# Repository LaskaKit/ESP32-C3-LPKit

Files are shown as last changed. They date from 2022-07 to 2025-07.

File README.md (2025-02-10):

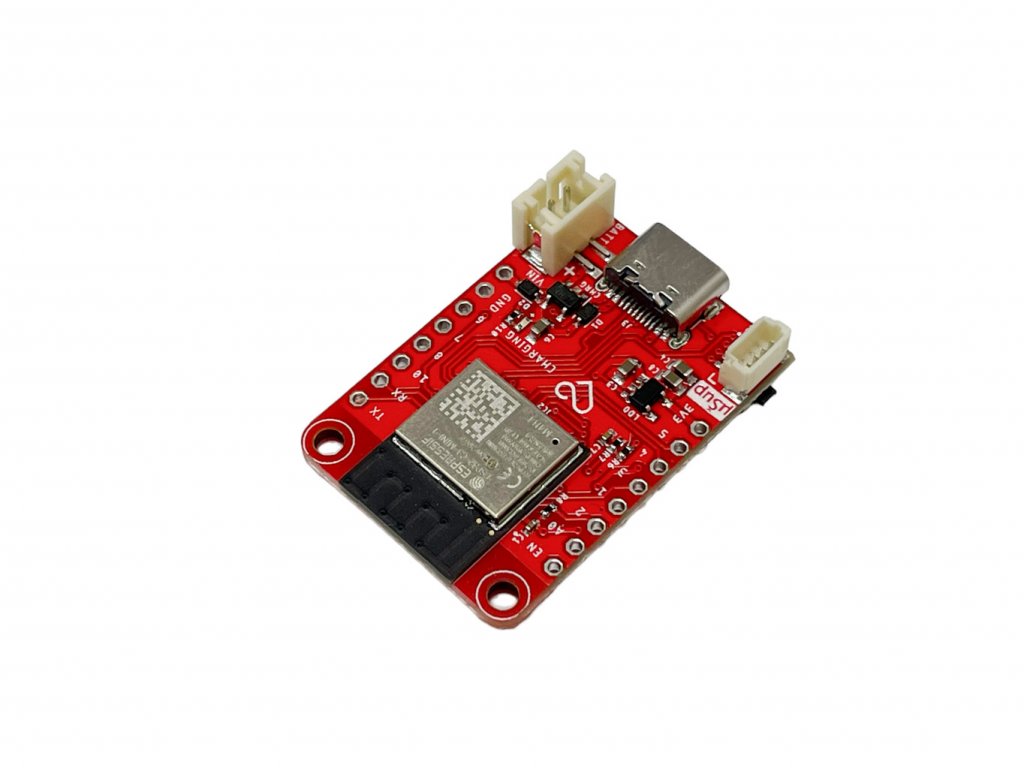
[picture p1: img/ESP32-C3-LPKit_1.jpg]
LaskaKit ESP32-C3-LPKit

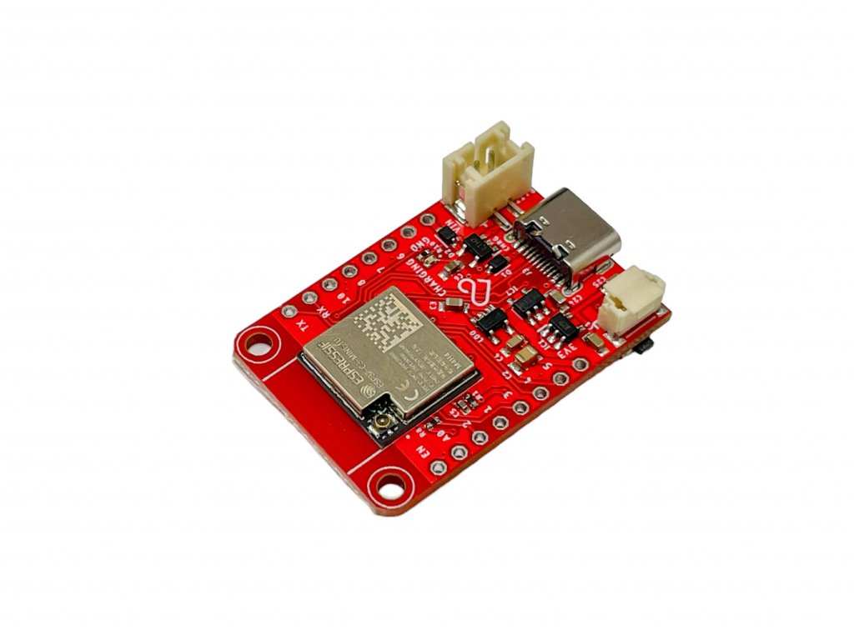
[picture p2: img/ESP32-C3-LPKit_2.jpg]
LaskaKit ESP32-C3-LPKit

# LaskaKit ESP32-C3-LPKit 

The LaskaKit [ESP32-C3-LPKit](https://www.laskakit.cz/laskkit-esp-12-board/?variantId=10482) development board is based on the popular Wi-Fi/Bluetooth ESP32-C3, which is widely supported by both the manufacturer and the bastling community.

The board is pin-to-pin and size compatible with the Wemos D1 Mini. Even though the [ESP32-C3-LPKit](https://www.laskakit.cz/laskkit-esp-12-board/?variantId=10482) includes a programmer like the popular Wemos D1 Mini, it achieves much lower power consumption and a low-power voltage regulator.</br>
This makes it much more energy efficient. So if you are looking for a compatible board and want to save power at the same time, then the ESP32-C3-LPKit is for you.

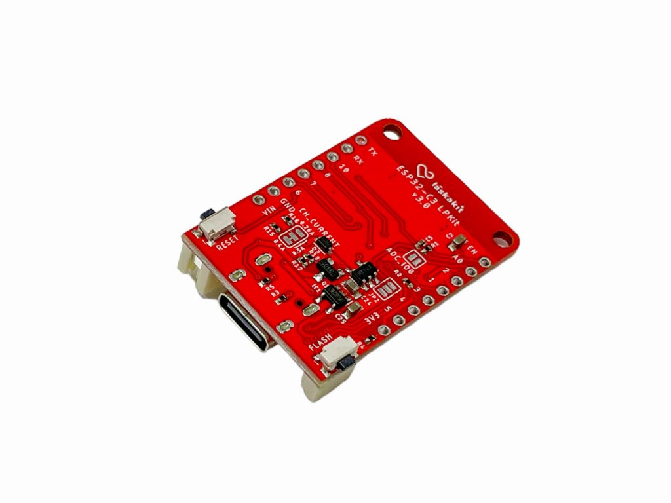
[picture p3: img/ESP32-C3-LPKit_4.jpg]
LaskaKit ESP32-C3-LPKit


The ESP32-C3-LPKit also includes a charging circuit for the battery, which is charged from USB-C or from the VIN pin. The charging current is selected by a solder bridge on the bottom of the board. The default setting is 400mA.</br>
The voltage measurement of the connected battery is disabled-unconnected by default (solder bridge on the bottom of the PCB). Either the battery (solder bridge) or the voltage connected on pin A0 (solder bridge) can be connected to the ESP32-C3. The measured voltage (battery/external input) is divided by voltage divider. The analog input for measured votlage is GPIO0.

It is necessary to add a definition on which PINs is I2C initiating the i2c module: Wire.begin(8, 10); // (8,10) -> ESP32-C3-LPKit v2; (19,18) -> ESP32-C3-LPKit v1

To program, you need to put the chip in bootloader mode.</br>
**Simply press the FLASH button and press and release RESET. Then release the FLASH button as well.**</br>
On Windows OS you should hear the characteristic sound of the newly connected device.</br>

For the older version of the ESP32-C3-LPKit you need a programmer, not only for them we have created a [suitable programmer](https://www.laskakit.cz/laskakit-ch9102-programmer-usb-c--microusb--uart/), with which programming this board will be a total breeze. When using our programmer, it is no longer necessary to press any buttons before the actual programming. Switching to programming mode is automatic.

| ESP module | 	ESP32-C3 | 
|---|---|
| Input voltage | 	3,7-8V | 
| Current in deep-sleep mode | 7μA | 
| Digital I/O Pins | 9 | 
| Analog inputs | 5 | 
| Dimensions |
| Length |34.2mm | 
| Width | 25.6mm | 
| Height | 7mm | 
| Weight | 8.26g | 

**The board is available on https://www.laskakit.cz/laskkit-esp-12-board/?variantId=10482**

Pinout
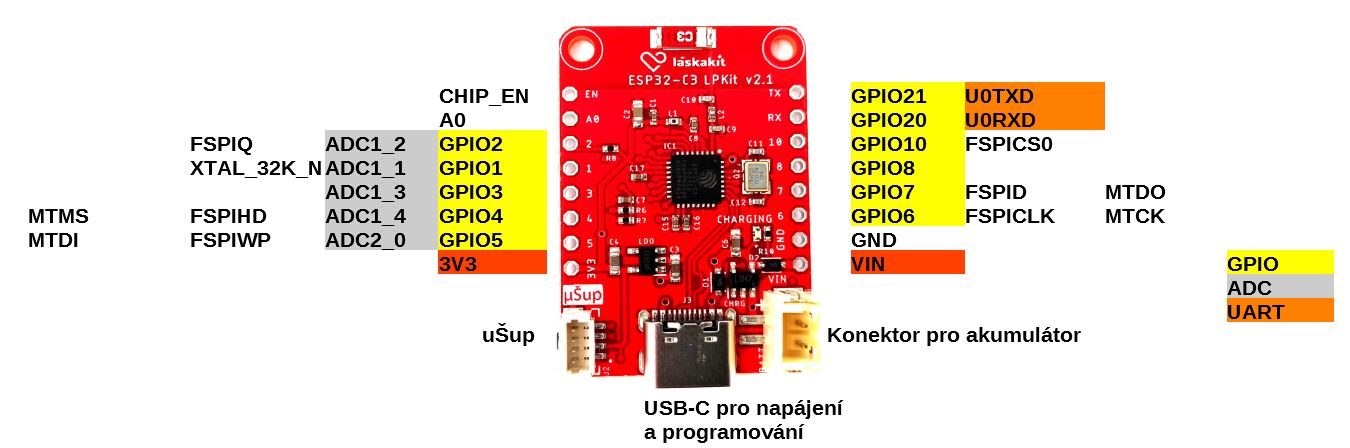
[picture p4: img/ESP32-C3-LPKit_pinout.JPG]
LaskaKit ESP32-C3-LPKit pinout

Battery voltage measurement connections for v3.2:
* Battery voltage measurement: left side JP2 + left side ADC_IO0
* Voltage measurement on pin A0, max. 4.2V: right side JP2 + left side ADC_IO0
* Voltage measurement on pin A0, max. 2.450V: JP2 not connected + right side ADC_IO0
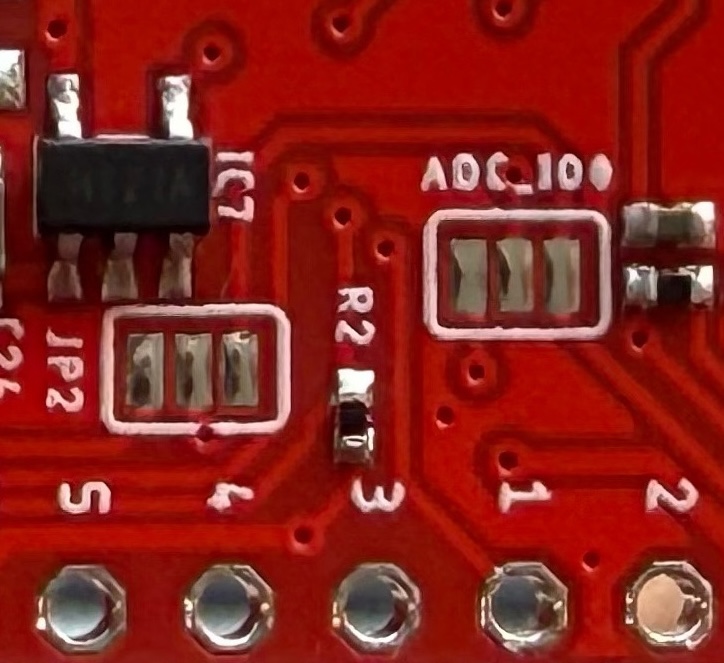
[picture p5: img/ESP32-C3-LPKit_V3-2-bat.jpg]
pinout LaskaKit ESP32-C3-LPKit


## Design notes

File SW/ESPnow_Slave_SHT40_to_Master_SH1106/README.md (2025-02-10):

# ESPnow - Slave odešle teplotu a vlhkost do Master, Master je zobrazí na OLED displeji

## SLAVE zařízení </br>
Vzorový kód pro využití ESPnow, přes které jsou odeslány teplota a vlhkost vzduchu</br>
Upozornění: je nezbytné zkopírovat MAC adresu z MASTER zařízení do SLAVE (masterMAC[])
Nejprve nahraj MASTER kód do ESP32-C3 LPkit a ESP32-C3 zobrazí svou MAC adresu,
kterou zapíšeš do SLAVE kódu a nahraješ do SLAVE zařízení.
</br>
## MASTER zařízení</br>
Vzorový kód pro využití ESPnow. SLAVE zařízení změří teplotu a vlhkost a odešle
do MASTER zařízení, které hodnoty vypíše do Serial a na OLED displej</br>
Upozornění: je nezbytné zkopírovat MAC adresu z MASTER zařízení do SLAVE (masterMAC[])
Nejprve nahraj MASTER kód do ESP32-C3 LPkit a ESP32-C3 zobrazí svou MAC adresu,
kterou zapíšeš do SLAVE kódu a nahraješ do SLAVE zařízení.</br>
</br>
## Hardware:</br>
https://www.laskakit.cz/laskkit-esp-12-board/?variantId=10482</br>
v popřípadě verze s externí anténou pak dokoupit anténu a pigtail</br>
https://www.laskakit.cz/pigtail-mhf3-ipex3-sma-female--kabel-1-15mm--15cm/</br>
https://www.laskakit.cz/laskakit-sht40-senzor-teploty-a-vlhkosti-vzduchu/</br>
https://www.laskakit.cz/laskakit-oled-displej-128x64-1-3--i2c/?variantId=11903</br>
</br>
## ESP32 package - 2.0.17 </br>
ESP library verze</br>
ESP32 library 3.0.x</br>
Podmínka: Tools -> pokud USB CDC On Boot is ENABLED potom</br>
Serial zmaneá nativní/vestavěné USB</br>
Tools -> pokud USB CDC On Boot je DISABLED potom</br>
Serial znamená UART (Piny RX a TX)</br>
</br>
ESP32 library 2.0.xy</br>
Podmínka: Tools -> USB CDC On Boot musí být zakázaný</br>
potom použijte USBSerial k poslání dat na nativní/vestavěné USB </br>

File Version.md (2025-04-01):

### Version 4.0
- Redo power line, LDO chnaged to RT9080
- + Neopixel LED
- + µŠup SPI connector
- ADC changed back to simplicity
#### Version 3.3
- Přidány I2C pullup rezistory
#### Version 3.2
- Změna jumperu ADC_IO0 na dvoucestný, aby bylo možné připojit pin A0 napřímo na IO0 bez napěťového děliče na desce.
#### Version 3.1
#### Version 3.0
- Předeláno na ESP32-C3-MINI (deep sleep 11 µA)
#### Version 2.1
- Doladěny hodnoty Pi článku antény
- IPEX anténa/SMD anténa - rozdělení na samostatné desky
- Přidána propojka na odpojení odporového děliče od baterie
#### Version 2.0
- Switched to bare C3 IC | Změna IO na holý C3
#### Version 1.2
- Adjusted resistor values in the resistance divider to 1M/1.3M, ADC max. input voltage stays the same. | Upraveny hodnoty rezistorů v odporovém děliči na 1M/1.3M, ADC max. vstupní napětí zůstává stejné. 
- BOOT button renamed to RESET | Přejmenováno tlačítko BOOT na RESET.
#### Version 1.1
- Voltager devider changed to 100k/130k ADC max. input voltage is 4.423 V | Dělič napětí změněn na 100k/130k ADC max. vstupní napětí je 4,423 V
#### Version 1.0
- Initial | Počáteční

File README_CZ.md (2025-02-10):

LaskaKit ESP32-C3-LPKit
LaskaKit ESP32-C3-LPKit

# LaskaKit ESP32-C3-LPKit 

Vývojová deska [LaskaKit ESP32-C3-LPKit](https://www.laskakit.cz/laskkit-esp-12-board/?variantId=10482) založena na populárním Wi-Fi/Bluetooth ESP32-C3, který je široce podporován jak výrobcem, tak i komunitou bastlířů. 

Deska je pinově a rozměrově kompatibilní s Wemos D1 Mini. I přesto, že [ESP32-C3-LPKit](https://www.laskakit.cz/laskkit-esp-12-board/) obsahuje programátor stejně jako populární Wemos D1 Mini, dosahuje daleko nižší spotřeby energie a ssamozřejmě i úspornější stabilizátor napětí.</br>
Díky tomu je energeticky mnohem úspornější. Pokud tedy hledáš kompatibilní desku a zároveň chcete šetřit energii, pak ESP32-C3-LPKit je pro Tebe jako určený.

LaskaKit ESP32-C3-LPKit

ESP32-C3-LPKit obsahuje i nabíjecí obvod pro akumulátor, ten se nabíjí z USB-C nebo z pinu VIN. Nabíjecí proud se volí pájecím mostem na spodní straně desky. Výchozí nastavení je 400mA.</br>
Měření napětí připojeného akumulátoru je ve výchozím stavu zakázáno-nepřipojeno (pájecí most na spodní straně DPS). Do ESP32-C3 může být připojeno měření napětí buď akumulátoru (pájecí most) nebo napětí připojené na pinu A0 (pájecí most). Napětí připojené na A0 je sníženo o poměr napěťového děliče. Analogový vstup pro měření napětí je GPIO0.

Je potřeba před iniciací i2c modulu přidat definici na kterých PINech jsou: Wire.begin(8, 10); // (8,10) -> ESP32-C3-LPKit v2; (19,18) -> ESP32-C3-LPKit v1

Pro naprogramování je potřeba dostat čip do režimu nahrávání. </br>
**Stačí zmáčknout tlačítko FLASH a zmáčknout a pustit RESET. Poté pustit i tlačítko FLASH** </br>
U OS Windows byste měli uslyšet charakteristický zvuk nově připojého zařízení.</br>

Pro staší verzi ESP32-C3-LPKit je potřeba programátor, nejen k nim jsme [vytvořili vhodný programátor](https://www.laskakit.cz/laskakit-ch340-programmer-usb-c--microusb--uart/), se kterým bude programování této desky naprostá hračka. Při použití tohoto našeho programátoru již není nutné před vlastním programováním mačkat žádná tlačítka. Přepnutí do režimu programování je automatické.</br>

| ESP modul | 	ESP32-C3 | 
|---|---|
| Vstupní napětí | 	3,7-8V | 
| Odběr proudu v deep-sleep módu | 7μA | 
| Digitální I/O Piny | 9 | 
| Analogové Vstupy | 5 |
| Rozměry |
| Délka |34.2mm | 
| Šířka | 25.6mm | 
| Výška | 7mm | 
| Váha | 8.26g | 

**LaskaKit ESP32-C3-LPkit najdeš na https://www.laskakit.cz/laskkit-esp-12-board/?variantId=10482**

Pinout ESP32-C3-LPKit vidíš níže
LaskaKit ESP32-C3-LPKit pinout
Propojení pro měření napětí baterie pro v3.2:
* Měření napětí na baterii: leva strana JP2 + levá strana ADC_IO0
* Měření napětí na pinu A0, max. 4.2V: pravá strana JP2 + levá strana ADC_IO0
* Měření napětí na pinu A0, max. 2.450V: JP2 nezapojeny + pravá strana ADC_IO0
LaskaKit ESP32-C3-LPKit pinout

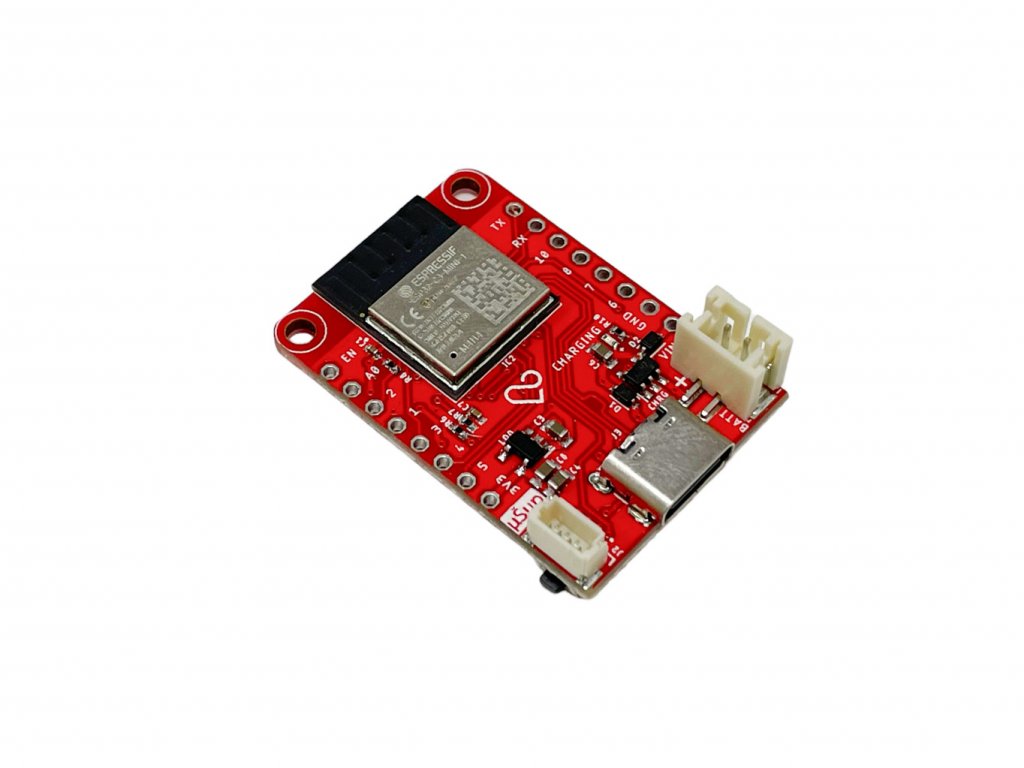
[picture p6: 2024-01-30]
img/ESP32-C3-LPKit_3.jpg

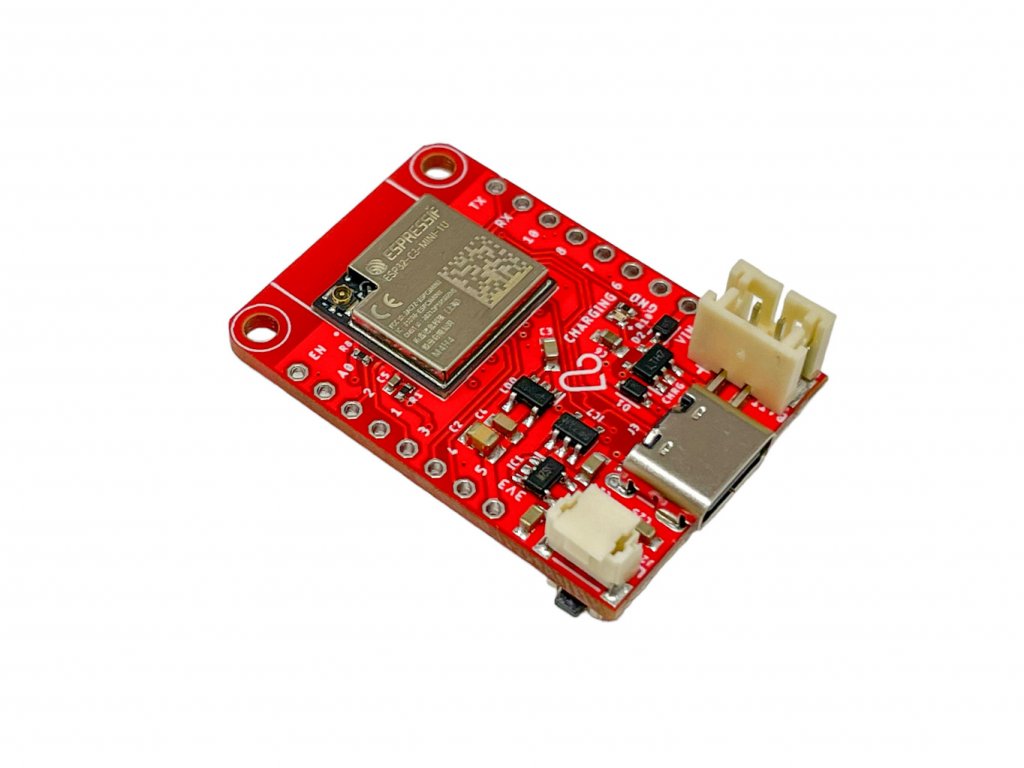
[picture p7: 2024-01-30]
img/ESP32-C3-LPKit_5.jpg

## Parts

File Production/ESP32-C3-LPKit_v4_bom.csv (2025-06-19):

Comment | Designator | Footprint | LCSC Part #
3.3k | R3 | R0402
4.7k | R14 | R0402
5.1k | R9 R10 | R0402
10k | R12 R15 R18 R22 | R0402
10uF/16V | C3 | C0603
22uF | C2 | C0603
47k | R19 R20 | R0402
100k | R13 | R0402
100nF | C1 | C0402
AO3401 | Q2 | SOT23
BAT60B | D3 | SOD323-R
DMG2305UX | Q6 | MICRO3 | C144153
ESP32-C3-MINI-1-N4 | IC2 | ESP32C3MINI1N4
JST-PH-2_SMD/SMD | P1 | B2B-PH-SM4 | C160352
JST-SH-4P | J2 | 1X04_1MM_RA_VERT | C371588
MMDT5401 | Q5 | SC70-6 | C54540
RED | CHARGING | CHIP-LED0603 | C2286
SK6812-EC20 | LED_IO9 | SK6812EC20
TP4054 | CH | SOT-23-5 | C32574
USB-C_GT-USB-7010B | J3 | G-SWITCH_GT-USB-7010B | C2837092
USUP_SPI_CONNECTOR_VERT | J1 | 1X06_1MM_RA_VERT | C145963
1.3M | R7 | R0402
1M | R6 | R0402
1k65 | R5 | R0402
3k3 | R11 | R0402
10k | R17 R21 | R0402
10uF/16V | C4 C6 C9 C13 | C0603
100nF | C5 C8 C14 | C0402
EN button | FLASH RESET | 1TS003B16003500A | C255808
LESD5D5.0CT1G | D8 D9 D10 | LESD5D50CT1G
RT9080-33GJ5 | LDO LDO_S | SOT94P280X100-5N

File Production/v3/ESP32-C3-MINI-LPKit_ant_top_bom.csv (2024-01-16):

Comment | Designator | Footprint | LCSC Part #
1k | R10 | R0402
1uF | C5 | C0402
1uF | C6 | C0603
10k | R1 R8 | R0402
22uF | C3 C24 | C0603
47uF | C1 C4 C25 | C0603
100uF | C2 | C0805
AP2191WG-7 | IC7 | SOT25 | C141321
BAT60B | D1 D2 | SOD323-R
ESP32-C3-MINI-1-N4 | IC2 | ESP32C3MINI1N4
HT7833 | LDO | SOT23-5
JST-PH-2/SMD | BATT | B2B-PH-SM4
JST-SH-4P | J2 | 1X04_1MM_RA_VERT | C371588
ME6211C33M5G | IC1 | SOT23-5
RED | CHARGING | CHIPLED_0402
TP4054 | CHRG | SOT-23-5
USB-C_2-16PIN | J3 | USBC_USB-C-16P-5 | C2837092
1.3M | R7 | R0402
1M | R6 | R0402
1TS003B-2000-3500A-CT | FLASH RESET | 1TS003B16003500A | C319396
1k65 | R15 | R0402
2M | R9 | R0402
3k3 | R16 | R0402
4.7k | R2 R4 | R0402
5k1 | R3 R5 | R0402
10k | R12 | R0402
100k | R13 | R0402
100nF | C7 | C0402
AO3401 | Q1 | SOT23
BAT60B | D3 | SOD323-R

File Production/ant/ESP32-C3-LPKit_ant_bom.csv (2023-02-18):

Comment | Designator | Footprint | LCSC Part #
1.3M | R7 | R0402
1M | R6 | R0402
1k | R10 | R0402
1uF | C3 C6 | C0603
2.4nH | L2 | L0402 | C90190
2.6p | C10 | C0402 | C2190109
2nH | L1 | L0402 | C145023
3.3p | C9 | C0402
10k | R8 | R0402
15p | C11 C12 | C0402
22uF | C2 C4 | C0603
40MHz | Q2 | 3.2X2.5_KX-7 | C9010
100nF | C1 C7 C8 C15 C16 C17 | C0402
BAT60B | D1 D2 | SOD323-R
CA-C03 | ANT | CA-C03
ESP32-C3FH4 | IC1 | QFN50P500X500X90-33N
HT7833 | LDO | SOT23-5
JST-PH-2/SMD | BATT | B2B-PH-SM4
JST-SH-4P | J2 | 1X04_1MM_RA_VERT | C239513
RED | CHARGING | CHIPLED_0402
TP4054 | CHRG | SOT-23-5
USB-C_2-16PIN | J3 | USBC_USB-C-16P-5 | C2837092
1TS003B-2000-3500A-CT | FLASH RESET | 1TS003B16003500A | C319396
1k65 | R15 | R0402
1uF | C5 | C0402
3k3 | R16 | R0402
5k1 | R3 R5 | R0402
10k | R1 R2 R4 R12 | R0402
10uF | C14 | C0603
100k | R13 | R0402
100nF | C13 | C0402
AO3401 | Q1 | SOT23
BAT60B | D3 | SOD323-R | C514095

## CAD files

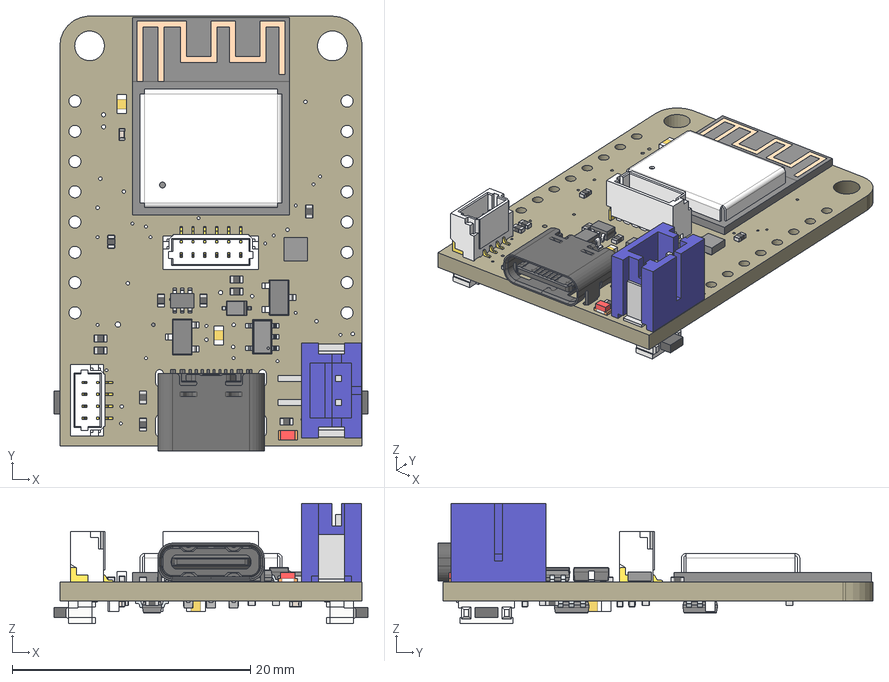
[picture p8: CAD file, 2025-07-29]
3D/ESP32-C3-LPKit_v4.step
26.4 x 36.5 x 10.1 mm
Board
Pin1 x 4
Pin2 x 4
CeramicBody x 4
LASKAKIT_HEART_4MM
LASKKIT_10MM_SILKSCREEN
1X04_1MM_RA_VERT
CHIP-LED0603
LESD5D50CT1G x 3
SC70-6
Pins
FilletPinL
FilletPinR
SOT23
2,5 x 2
ESP32C3MINI1N4
PinsArrayL
PinsArrayR
PinsArrayL (1) x 2
PinsArrayR (1) x 2
1TS003B16003500A x 2
C0603 x 6
R0402 x 17
MICRO3
USUP_4MM_SILKSCREEN
1X06_1MM_RA_VERT
B2B-PH-SM4
G-SWITCH_GT-USB-7010B

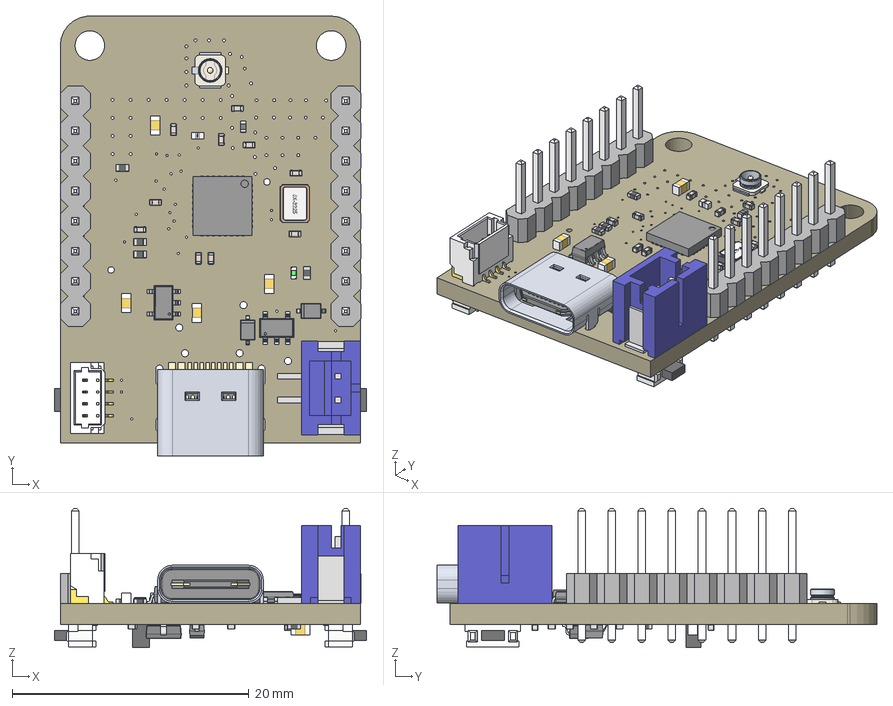
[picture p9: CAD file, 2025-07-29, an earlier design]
3D/old/ESP32-C3-LPKit_ipex_v2-1.step
26.4 x 37.2 x 11.8 mm
Board
L0402
base
SolderPad x 2
LASKAKIT_HEART_4MM
LASKKIT_10MM_SILKSCREEN
USUP_4MM_SILKSCREEN
1X04_1MM_RA_VERT
B2B-PH-SM4
U.FL_REDUCED_FOOTPRINT
USBC_USB-C-16P-5
CHIPLED_0402
SOT23
ThermalPin
PinsArrayLR
PinsArrayTB
PinsArrayL
PinsArrayR
PinsArrayL (1)
PinsArrayR (1)
3.2X2.5_KX-7
SMT-JUMPER_2_NO_SILK
Pin1 x 12
Pin2 x 12
CeramicBody x 12
1X08 x 2
FilletPinL x 3
FilletPinR x 3
2,5 x 2
1TS003B16003500A x 2
C0603 x 5
R0402 x 13

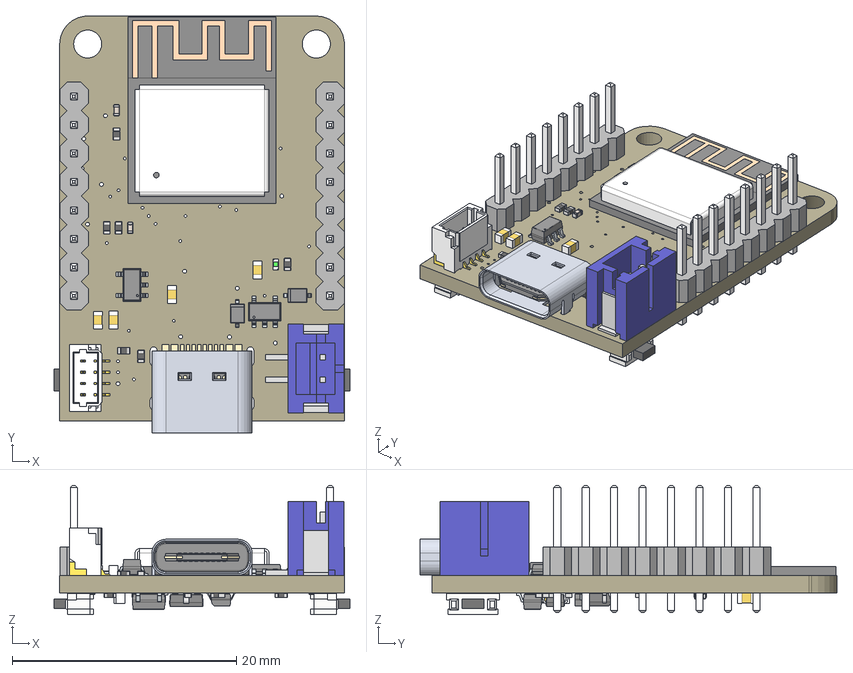
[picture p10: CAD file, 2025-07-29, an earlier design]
3D/old/ESP32-C3-LPKit_v3_3.step
26.4 x 37.2 x 11.5 mm
Board
Pin1 x 3
Pin2 x 3
CeramicBody x 3
LASKAKIT_HEART_4MM
LASKKIT_10MM_SILKSCREEN
USUP_4MM_SILKSCREEN
1X04_1MM_RA_VERT
1X08 x 2
B2B-PH-SM4
USBC_USB-C-16P-5
CHIPLED_0402
FilletPinL x 3
FilletPinR x 3
SOT23
2,5 x 2
ESP32C3MINI1N4
PinsArrayL
PinsArrayR
PinsArrayL (1) x 2
PinsArrayR (1) x 2
SOT25
1TS003B16003500A x 2
C0603 x 7
R0402 x 15

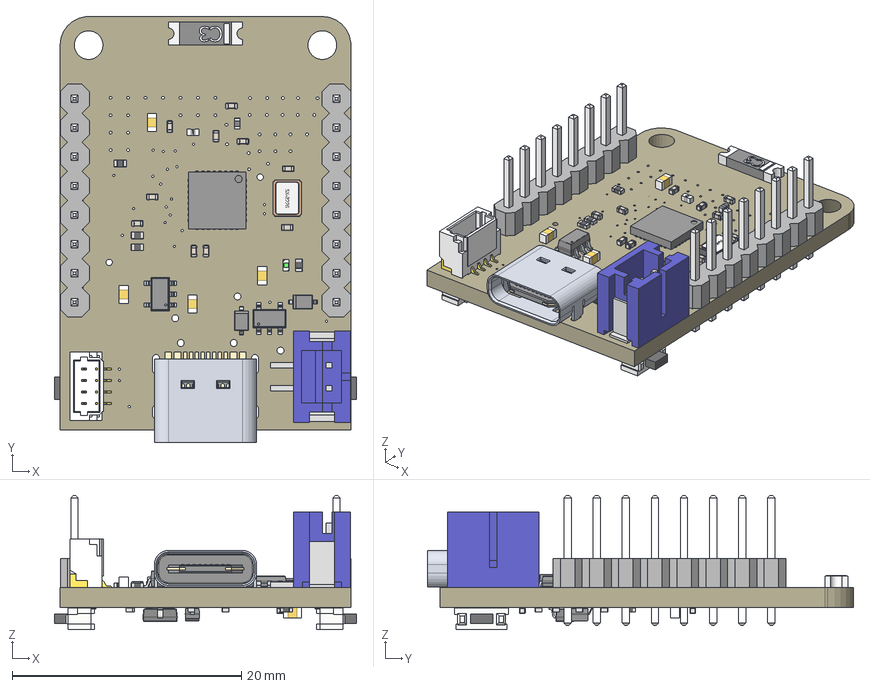
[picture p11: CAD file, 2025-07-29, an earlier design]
3D/old/ESP32-C3-LPKit_ant_v2-1.step
26.4 x 37.2 x 11.7 mm
Board
MainBody
Left
Right
SilkScreenMark
C3
L0402
base
SolderPad x 2
LASKAKIT_HEART_4MM
LASKKIT_10MM_SILKSCREEN
USUP_4MM_SILKSCREEN
1X04_1MM_RA_VERT
B2B-PH-SM4
USBC_USB-C-16P-5
CHIPLED_0402
SOT23
ThermalPin
PinsArrayLR
PinsArrayTB
PinsArrayL
PinsArrayR
PinsArrayL (1)
PinsArrayR (1)
3.2X2.5_KX-7
Pin1 x 12
Pin2 x 12
CeramicBody x 12
1X08 x 2
FilletPinL x 3
FilletPinR x 3
2,5 x 2
1TS003B16003500A x 2
C0603 x 5
R0402 x 13

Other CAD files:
3D/ESP32-C3-LPKit_v3_3.f3d
3D/ESP32-C3-LPKit_v4.f3d
3D/old/ESP32-C3-LPKit_v3_3.f3d

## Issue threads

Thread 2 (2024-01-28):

I2C pin warning (pins 1,2 don't work, only pins 8,10 do)

3top1a, 2024-01-28:
Hi,

I've just spent 5 days debugging an I2C issue, just to find out that you can't use I2C on pins 1 and 2.
Maybe rewrite the warning to say "not only do you need to use Wire.begin(8, 10) but also you need to use pins 8 and 10 otherwise I2C won't work"?

Thanks.

Konstantin-G, 2024-01-29:
Hi, we have not checked if there pins working for I2C or not. We have dedicated pins 8 and 10 for I2C with connector.
What did you try to connect to I2C? Does it have pull-ups? because IO2 already have 10k pull-up...

3top1a, 2024-01-29:
I have tried, and it did show up on a I2C scanner, but no data got through. It's possible the ESP C3 chip reserves those pins.

Konstantin-G, 2024-01-30:
you did not answer. What did you try to connect to I2C? Does it have pull-ups?

3top1a, 2024-01-30:
Ah, sorry. I was connecting a BNO085 IMU. [I tried connecting a 2K resistor to SDA but nothing.](https://forums.adafruit.com/viewtopic.php?p=1001700#p1001700)

Konstantin-G, 2024-01-31:
ohh, I think it is something with Adafruit level shifter and I2C pull-ups on sensor.

Closed 2024-01-31.

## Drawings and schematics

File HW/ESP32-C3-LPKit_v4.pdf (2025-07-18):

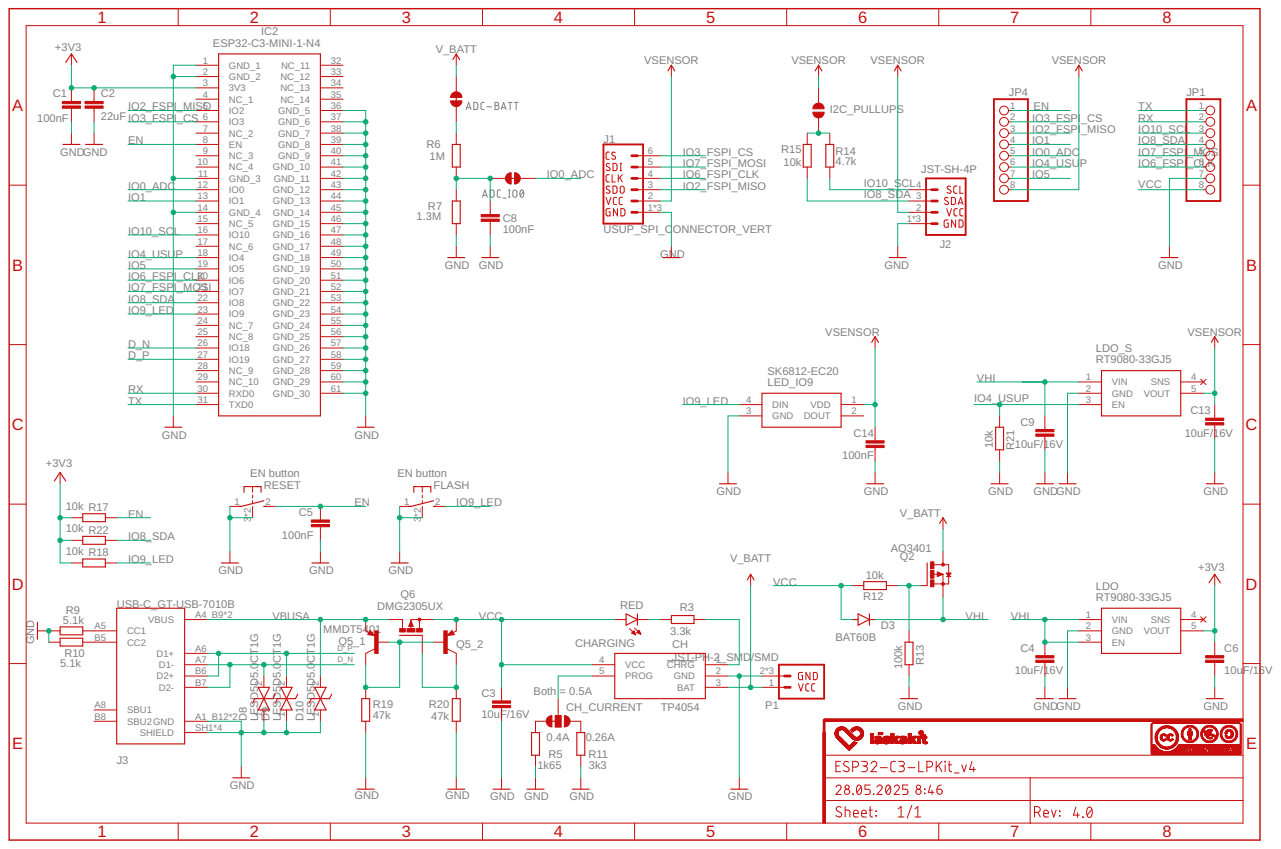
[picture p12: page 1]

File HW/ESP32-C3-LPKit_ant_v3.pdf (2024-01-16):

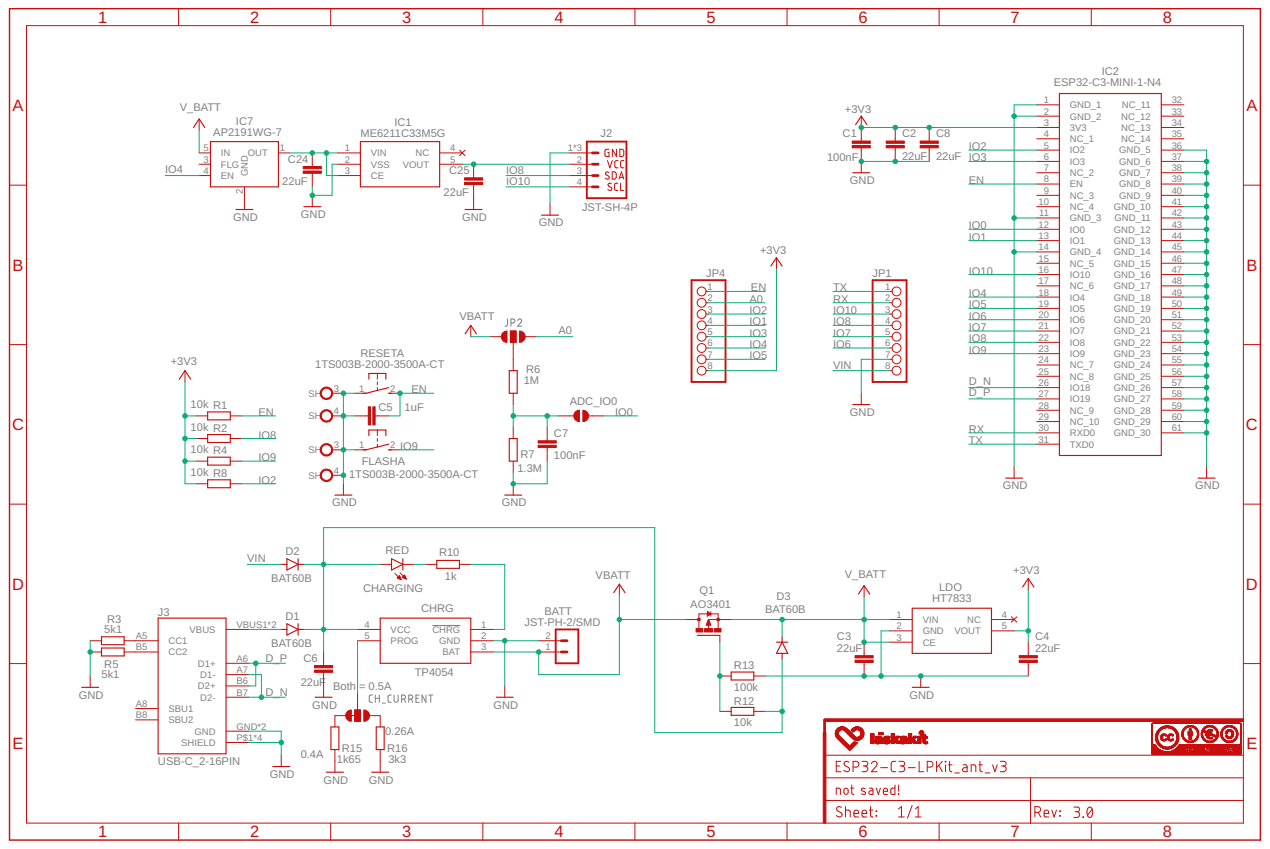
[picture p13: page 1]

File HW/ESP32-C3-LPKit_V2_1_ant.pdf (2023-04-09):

## 8 JP1

8JP4

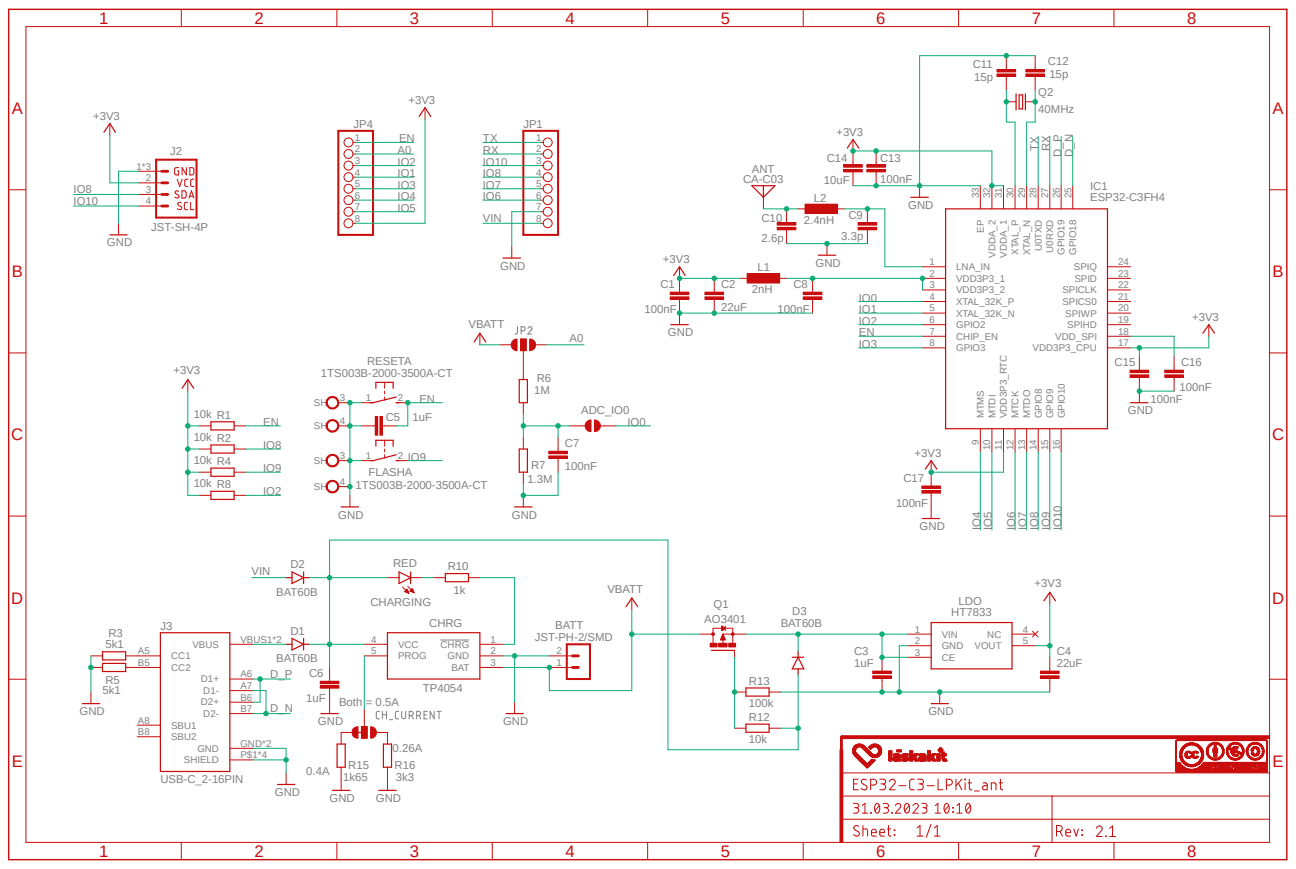
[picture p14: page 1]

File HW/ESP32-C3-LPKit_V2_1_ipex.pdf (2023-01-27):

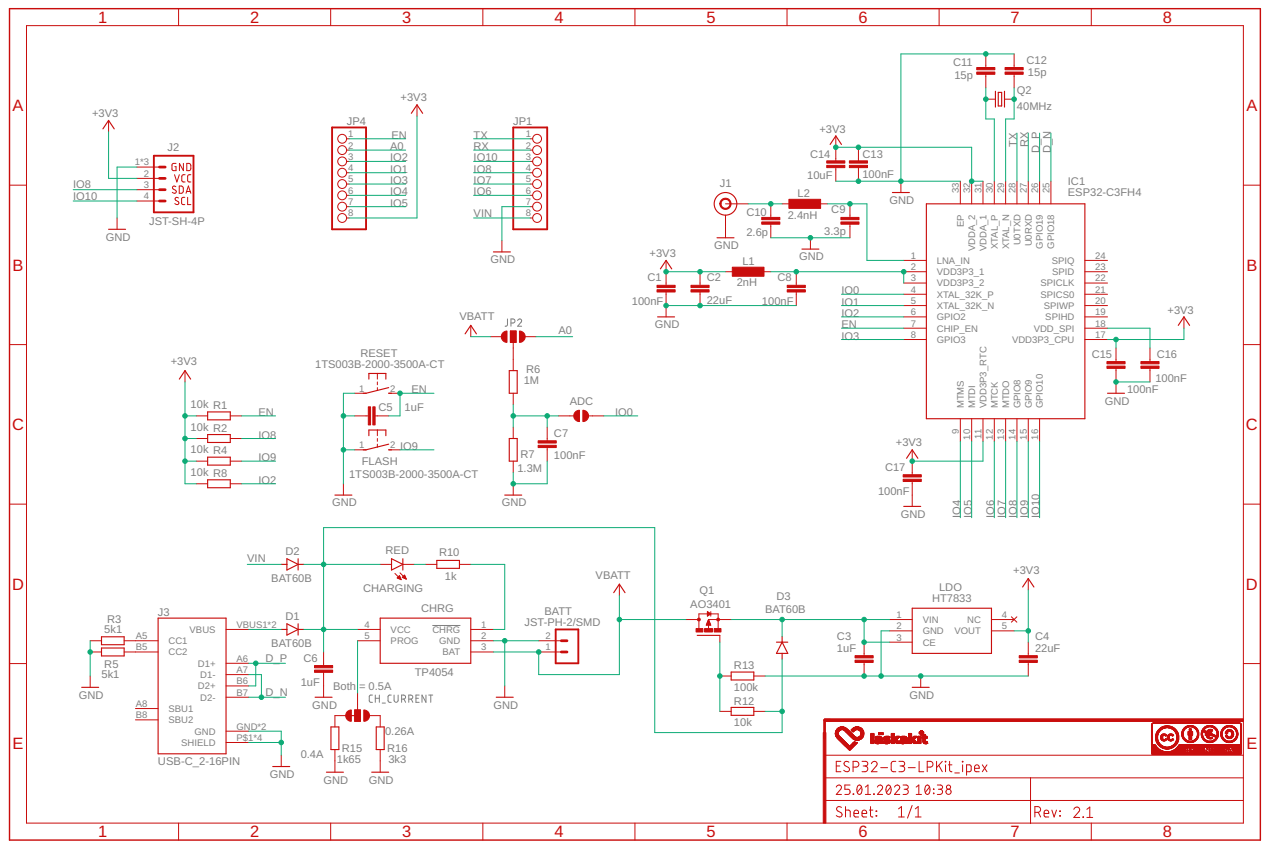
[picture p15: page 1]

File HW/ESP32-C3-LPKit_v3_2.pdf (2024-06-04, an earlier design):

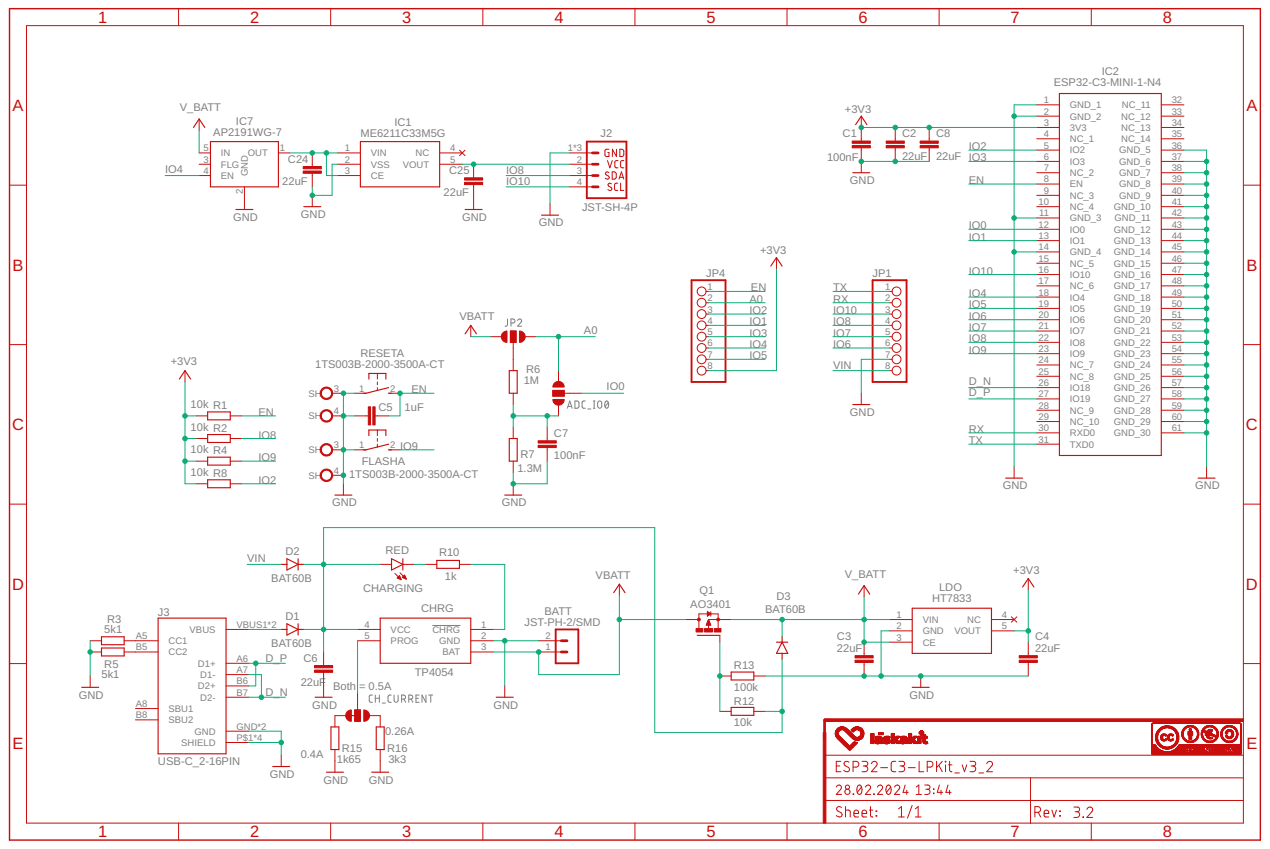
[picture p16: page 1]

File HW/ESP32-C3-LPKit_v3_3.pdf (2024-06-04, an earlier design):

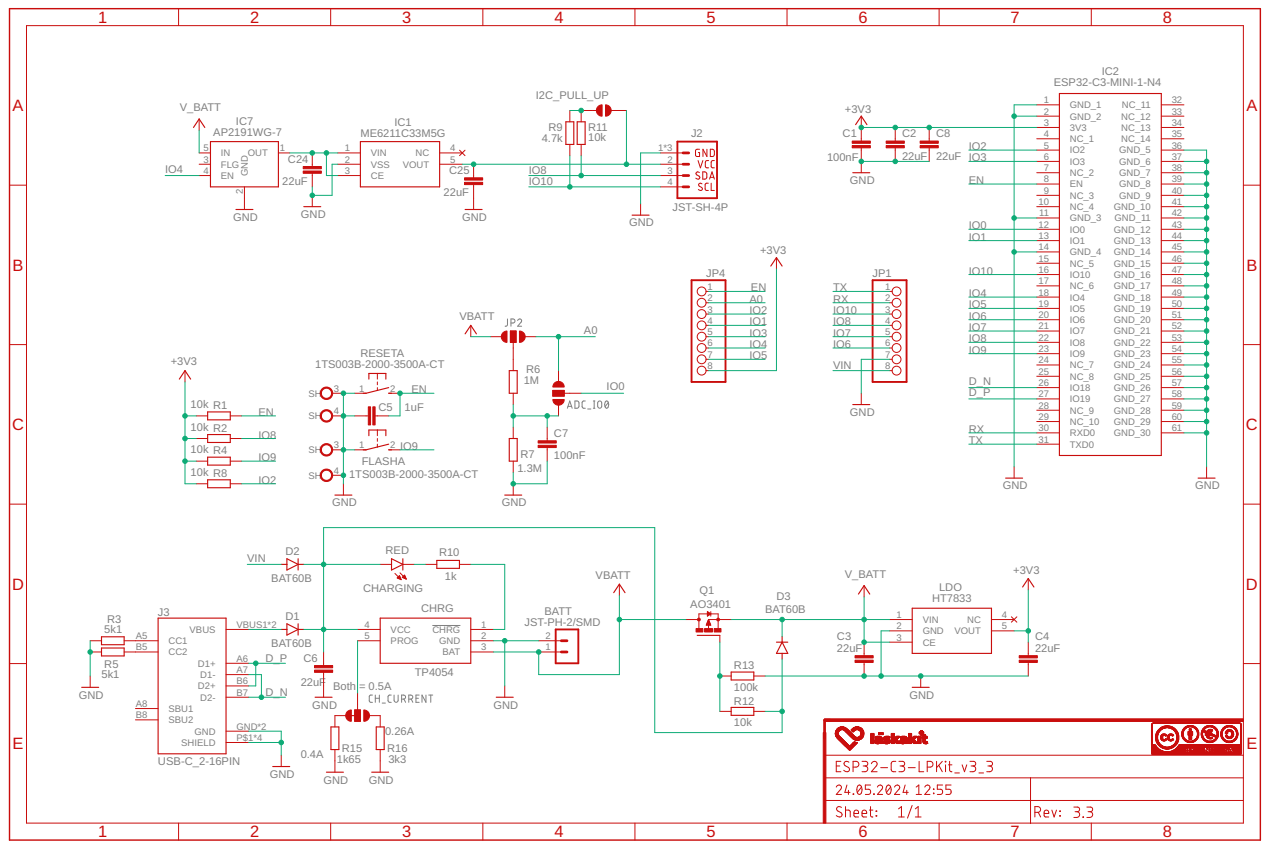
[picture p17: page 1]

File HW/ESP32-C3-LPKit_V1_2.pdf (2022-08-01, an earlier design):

## 8 JP1

# EN EN

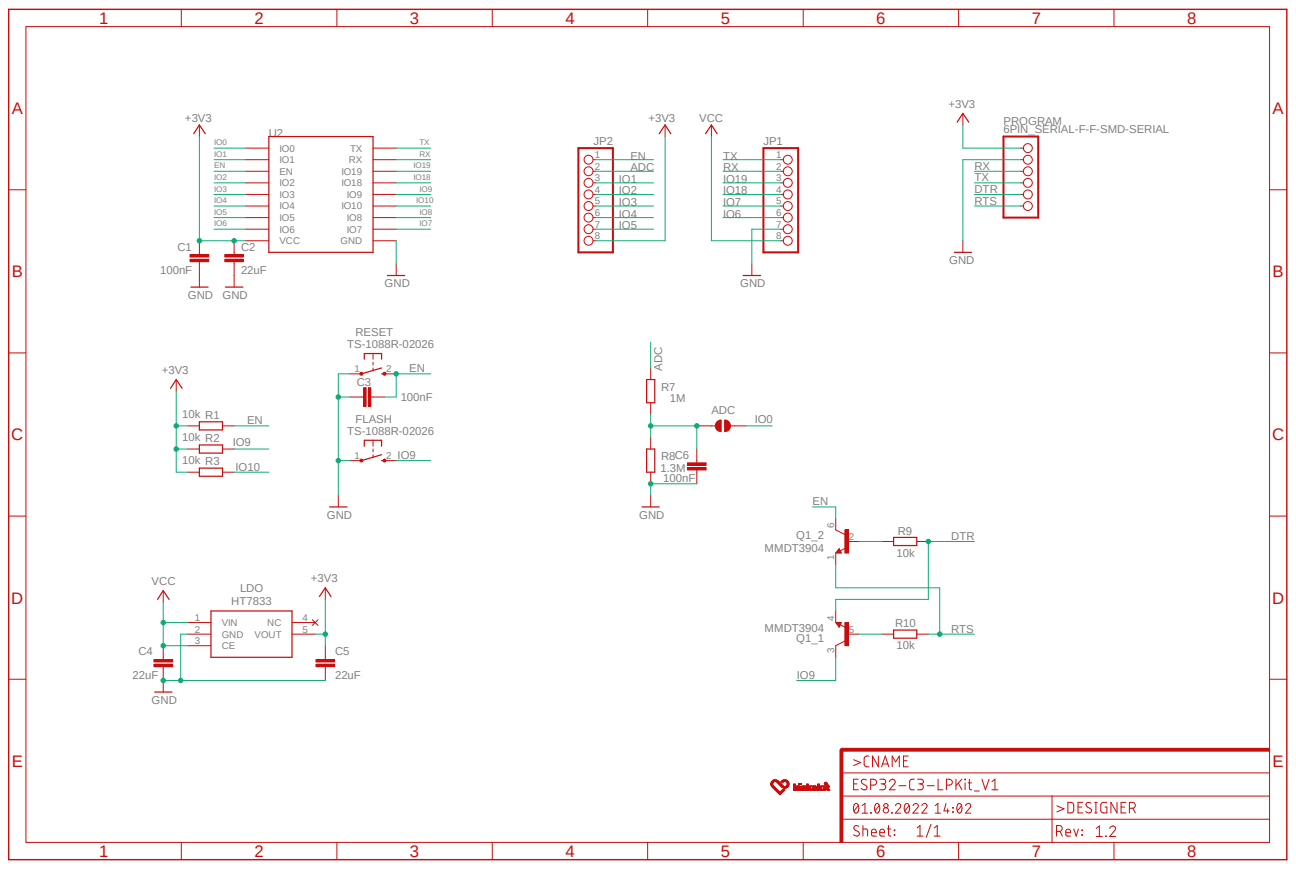
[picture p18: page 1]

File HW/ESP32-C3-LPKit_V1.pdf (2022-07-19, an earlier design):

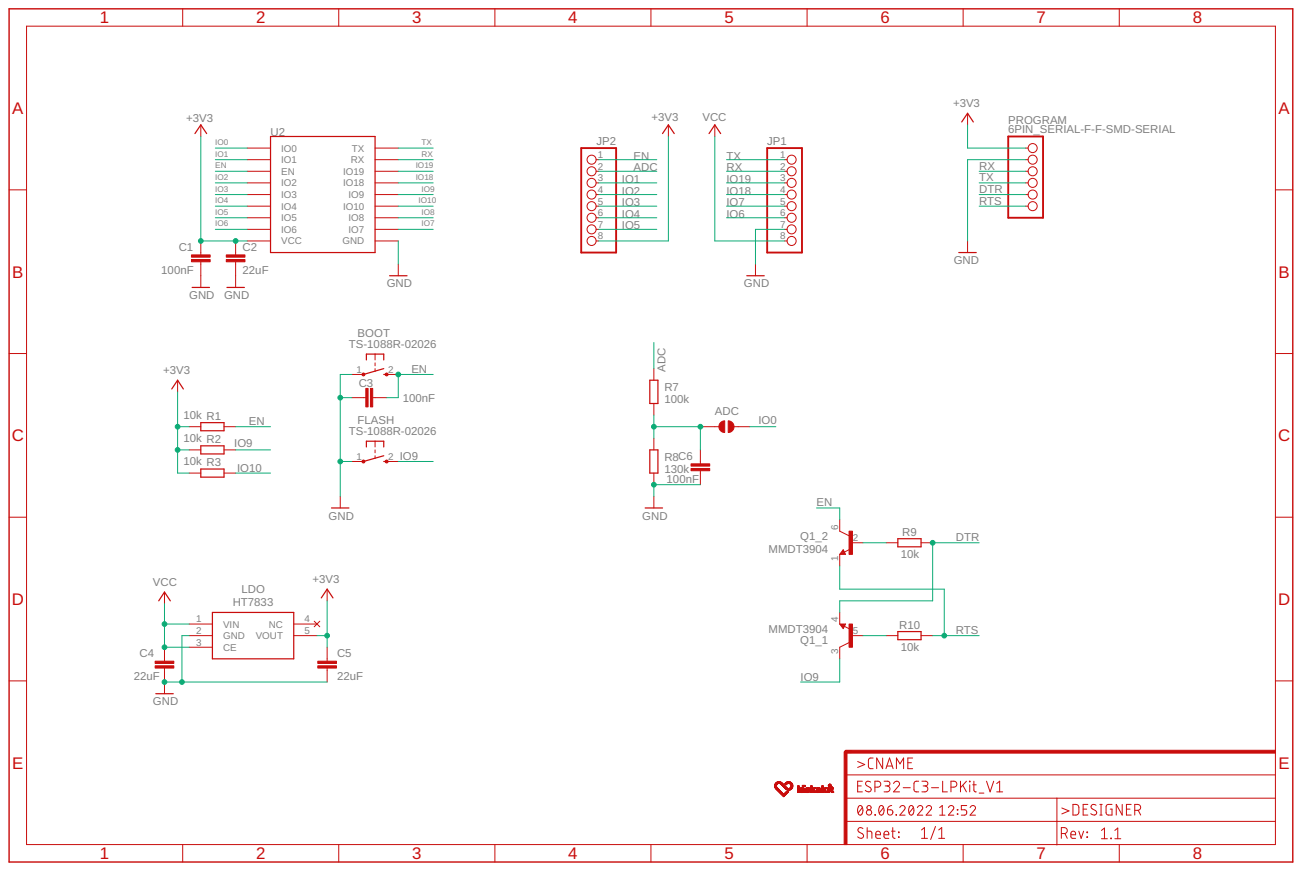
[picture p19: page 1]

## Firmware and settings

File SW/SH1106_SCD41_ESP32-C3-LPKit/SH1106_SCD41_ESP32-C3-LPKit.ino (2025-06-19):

/*
* Example code for ESP32-C3_OLED_kit 
*
* ESP32-C3-LPKit v3.x reads data from SCD41
* It shows the CO2, temperature, humidity
* to OLED display
*
* Hardware:
* ESP32-C3-LPKit v3.x - https://www.laskakit.cz/laskkit-esp-12-board/
* SCD41 Senzor CO2, teploty a vlhkosti vzduchu  - https://www.laskakit.cz/laskakit-scd41-senzor-co2--teploty-a-vlhkosti-vzduchu/
* OLED displej 128x64 1.3" I²C - https://www.laskakit.cz/laskakit-oled-displej-128x64-1-3--i2c/
*
* Library:
* https://github.com/sparkfun/SparkFun_SCD4x_Arduino_Library
* https://github.com/adafruit/Adafruit_SH110x
*
* 
* !!! ESP library version !!!
* ESP32 library 3.0.x
* Condition: Tools -> if USB CDC On Boot is ENABLED then
* Serial means native USB
* Tools -> if USB CDC On Boot is DISABLED then
* Serial means UART
* ---
* ESP32 library 2.0.xy
* Condition: Tools -> USB CDC On Boot must be disabled
* use USBSerial to send data through native USB 
*
* Board: ESP32-C3 Dev Module
*/


#include <Wire.h>
#include <Adafruit_GFX.h>
#include <Adafruit_SH110X.h>

#include "SparkFun_SCD4x_Arduino_Library.h"

// fonts
#include "DSEG14_Classic_Bold_32px.h"
#include "DSEG14_Classic_Bold_12px.h"

// OLED 
// uncomment only one of them, check the solderbridge on LaskaKit OLED
//#define i2c_Address 0x3c //initialize with the I2C addr 0x3C
#define i2c_Address 0x3d  //initialize with the I2C addr 0x3D

#define SCREEN_WIDTH 128  // OLED display width, in pixels
#define SCREEN_HEIGHT 64  // OLED display height, in pixels
#define OLED_RESET -1     //   QT-PY / XIAO
Adafruit_SH1106G display = Adafruit_SH1106G(SCREEN_WIDTH, SCREEN_HEIGHT, &Wire, OLED_RESET);

int co2 = 0;
float temperature = 0.0;
int humidity = 0;

// SCD41
SCD4x SCD41;

#define PIN_ON    4    

void setup() {
  // Speed of Serial
  Serial.begin(115200);
  
  pinMode(PIN_ON, OUTPUT);      // Set EN pin for second stabilisator as output
  digitalWrite(PIN_ON, HIGH);   // Turn on the second stabilisator
  
  // set dedicated I2C pins 8 - SDA, 10 SCL for ESP32-C3-LPKit
  Wire.begin(8, 10);

  /*----- OLED sequence ------*/
  delay(250);                        // wait for the OLED to power up
  display.begin(i2c_Address, true);  // Address 0x3C default
  //display.setContrast (0); // dim display

  // Clear the buffer.
  display.clearDisplay();
  // Set font
  display.setFont(&DSEG14_Classic_Bold_12);
  // Set color of text
  display.setTextColor(SH110X_WHITE);
  // Set position
  display.setCursor(0, 20);
  // Write text
  display.println("Waiting  for");
  display.println("");
  display.println("measurement");
  // Update display
  display.display();

  /*----- SCD41 sequence ------*/
  //             begin, autoCalibrate
  //               |      |
  if (SCD41.begin(false, true) == false) {
    Serial.println("SCD41 was not set correctly. Check the connection.");
    while (1)
      ;
  }

  if (SCD41.startLowPowerPeriodicMeasurement() == true) {
    Serial.println("Low power mode enabled.");
  }
}


void loop() {

  if(SCD41.readMeasurement())  // wait for a new data (approx 30s)
  {
    /*----- SCD41 sequence ------*/
    co2 = SCD41.getCO2();
    temperature = SCD41.getTemperature();
    humidity = SCD41.getHumidity();

    Serial.println();

    Serial.print("CO2(ppm):");
    Serial.println(co2);

    Serial.print("\tTemperature(C):");
    Serial.println(temperature);

    Serial.print("\tHumidity(%RH):");
    Serial.println(humidity);

    /*----- OLED sequence ------*/
    display.clearDisplay();
    // CO2
    display.setFont(&DSEG14_Classic_Bold_32);
    display.setTextColor(SH110X_WHITE);
    display.setCursor(10, 40);
    display.println(co2);

    // Temperature
    display.setFont(&DSEG14_Classic_Bold_12);
    display.setTextColor(SH110X_WHITE);
    display.setCursor(20, 60);
    display.println(temperature);

    // Humidity
    display.setFont(&DSEG14_Classic_Bold_12);
    display.setTextColor(SH110X_WHITE);
    display.setCursor(80, 60);
    display.println(humidity);

    // update display
    display.display();

    digitalWrite(PIN_ON, LOW);   // Turn off the second stabilisator
    // go to sleep for 1 minute
    Serial.flush();
    esp_sleep_enable_timer_wakeup(60 * 1000000);
    esp_deep_sleep_start();
  }

  delay(500);
}

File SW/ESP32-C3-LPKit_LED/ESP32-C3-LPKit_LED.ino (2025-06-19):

/*
* This example code is used for LaskaKit LaskaKit ESP32-C3-LPKit board  https://www.laskakit.cz/laskkit-esp-12-board/
* ESP32-C3-LPKit just changing LED color 
* 
* Made by (c) laskakit.cz 2025
* 
*/

#include <Adafruit_NeoPixel.h>
#define PIN_ON 4
#define PIN_LED 9

Adafruit_NeoPixel pixels = Adafruit_NeoPixel(1, PIN_LED, NEO_GRB + NEO_KHZ800);

void setup() {
  Serial.begin(115200);
  pinMode(PIN_ON, OUTPUT);      // Set EN pin for second stabilisator as output
  digitalWrite(PIN_ON, HIGH);   // Turn on the second stabilisator

  pixels.begin();
  pixels.setBrightness(10);
}

void loop() {
     
  pixels.setPixelColor(0, pixels.Color(255, 0, 0)); // R, G, B
  pixels.show();

  delay(1000);

  pixels.setPixelColor(0, pixels.Color(0, 255, 0)); // R, G, B
  pixels.show();

  delay(1000);

  pixels.setPixelColor(0, pixels.Color(0, 0, 255)); // R, G, B
  pixels.show();

  delay(1000);

  pixels.setPixelColor(0, pixels.Color(255, 255, 255)); // R, G, B
  pixels.show();

  delay(1000);

}

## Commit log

2022-07-19 new ver
    [ESP32-C3-LPKit_V1_top_bom.csv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]
2022-08-01 new version, see version.md
    [ESP32-C3-LPKit_V1_top_bom.csv]
2022-11-21 new version
    [ESP32-C3-LPKit_v2_bom.csv, ESP32-C3-LPKit_v2_bottom_bom.csv, ESP32-C3-LPKit_v2_top_bom.csv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]
2023-02-10 minor changes
    [ESP32-C3-LPKit_V1_top_bom.csv, ESP32-C3-LPKit_ant_bom.csv, ESP32-C3-LPKit_ipex_bom.csv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]
2023-02-18 data update
    [ESP32-C3-LPKit_ant_bom.csv, ESP32-C3-LPKit_ipex_bom.csv, ESP32-C3-LPKit_ipex_bottom_bom.csv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]
2023-10-03 new test data
    [ESP32-C3-LPKit_ant_v3_top_bom.csv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]
2023-12-26 Update README_CZ.md
    I2C pinout
2023-12-26 Update README.md
    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
2024-01-16 new data
    [ESP32-C3-MINI-LPKit_ant_top_bom.csv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]
2024-03-15 updated, see version.md
    [ESP32-C3-LPKit_ant_v3_2_bottom_bom.csv, ESP32-C3-LPKit_ant_v3_2_top_bom.csv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]
2024-06-04 update to new ver, added ADC jumper
2024-08-11 Update SH1106_SCD41_ESP32-C3-LPKit.ino
    ESP32 library version
2024-08-11 Update deepsleep_test.ino
    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
2024-08-11 Update deepsleep_test.ino
    No second regulator, codes for GPIO en/dis removed
2024-08-11 Update SH1106_SCD41_ESP32-C3-LPKit.ino
    The control of I2C power
2024-08-11 Update wifi_signal_oled.ino
    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
2024-08-11 Update wifi_signal_oled.ino
    minor bug fix
    [wifi_signal_oled.ino]
2024-08-11 Update SH1106_SCD41_ESP32-C3-LPKit.ino
    Serial bug fix
    [SH1106_SCD41_ESP32-C3-LPKit.ino]
2024-08-11 Update deepsleep_test.ino
    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
    [deepsleep_test.ino]
2024-08-11 Update wifi_signal_oled.ino
    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
    [wifi_signal_oled.ino]
2025-01-30 I2C pin def
2025-02-10 added info about battery measurement
2025-05-22 new tes version
    [ESP32-C3-LPKit_ant_bom.csv, ESP32-C3-LPKit_ant_v3_2_bottom_bom.csv, ESP32-C3-LPKit_ant_v3_2_top_bom.csv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]
2025-06-19 new ver v4.0 see version.md
    [ESP32-C3-LPKit_v4_bom.csv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]
2025-07-29 forder change
    [ESP32-C3-LPKit_ant_v2-1.step, ESP32-C3-LPKit_ipex_v2-1.step, ESP32-C3-LPKit_v3_3.f3d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]
